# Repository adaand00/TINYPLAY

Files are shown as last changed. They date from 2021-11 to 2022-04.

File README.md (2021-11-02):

# TINYPLAY
A tiny (46x25mm) game console using the attiny5

## Development
 The code is fully contained in main.c. The code was compiled and uploaded with microchip studio, using the standard settings for "attiny5 release". The gerber files were made in fusion360.
 
 
 

## BOM
* PCB
* ATTINY5-TS
* 8 bit Shift register - TI: SN74HCS164DR
* cr2032 battery holder - Linx: BAT-HLD-001-THM-TR 
* SMD slide switch - C&K: JS102011SAQN 
* 15x 0805 red LEDs
* 2x 6x6mm tactile buttons
* sod123 diode
* various 0603 resistors and capacitors
 
 ## Future development
  - [ ] Make it smaller (!Important!)
  - [ ] Improve programming headers
  - [ ] Make the game more fun
  - [ ] Add more pixels

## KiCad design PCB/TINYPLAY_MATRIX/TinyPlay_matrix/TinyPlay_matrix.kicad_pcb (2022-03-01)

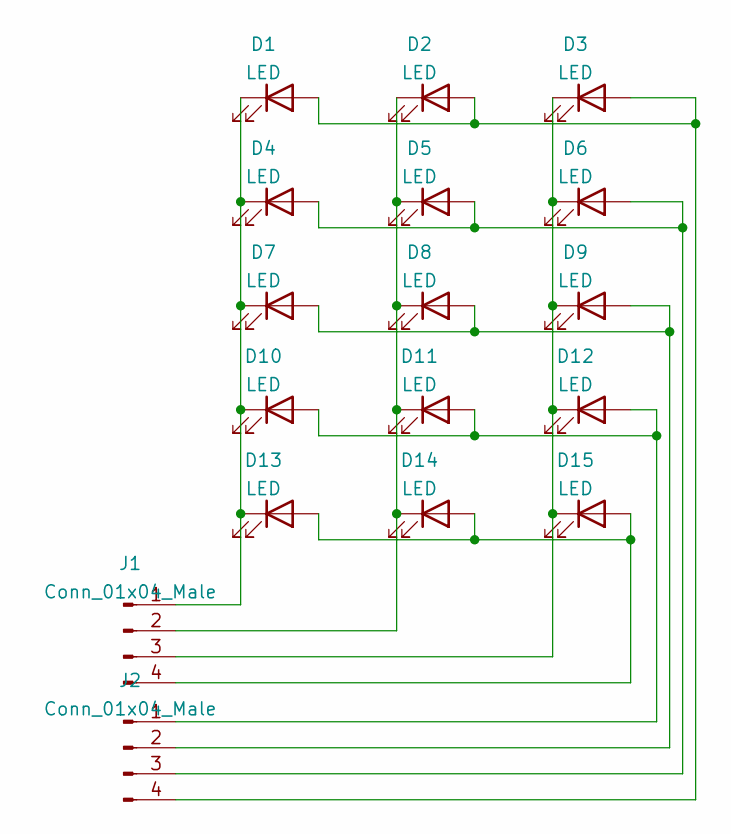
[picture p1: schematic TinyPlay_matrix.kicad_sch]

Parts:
D1, D2, D3, D4, D5, D6, D7, D8, D9, D10, D11, D12, D13, D14, D15: LED; LED_0603_1608Metric_Pad1.05x0.95mm_HandSolder
J1, J2: Conn_01x04_Male; PinHeader_1x04_P1.27mm_Vertical

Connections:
unnamed: D1.1 (K), D4.1 (K), D7.1 (K), D10.1 (K), D13.1 (K), J1.1
unnamed: D1.2 (A), D2.2 (A), D3.2 (A), J2.4
unnamed: D4.2 (A), D5.2 (A), D6.2 (A), J2.3
unnamed: D7.2 (A), D8.2 (A), D9.2 (A), J2.2
unnamed: D10.2 (A), D11.2 (A), D12.2 (A), J2.1
unnamed: D2.1 (K), D5.1 (K), D8.1 (K), D11.1 (K), D14.1 (K), J1.2
unnamed: D3.1 (K), D6.1 (K), D9.1 (K), D12.1 (K), D15.1 (K), J1.3
unnamed: D13.2 (A), D14.2 (A), D15.2 (A), J1.4

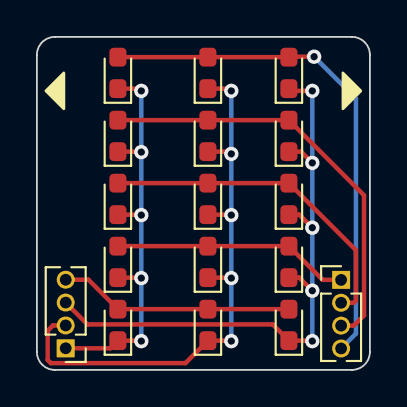
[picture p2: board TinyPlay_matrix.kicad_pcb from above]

Board: 2 copper layers, 18.5 x 18.5 mm, 17 parts (0 on the bottom side), 8 nets.

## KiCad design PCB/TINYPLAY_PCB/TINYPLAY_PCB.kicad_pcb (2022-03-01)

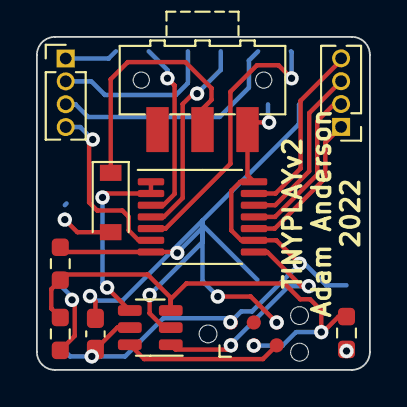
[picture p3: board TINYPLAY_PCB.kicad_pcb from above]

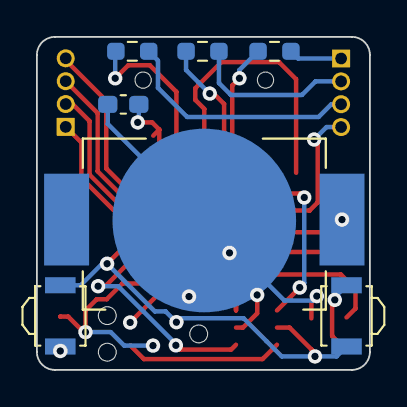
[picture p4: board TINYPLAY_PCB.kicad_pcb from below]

Board: 2 copper layers, 18.5 x 18.5 mm, 18 parts (7 on the bottom side), 21 nets.

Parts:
BT1: Battery_Cell; BAT_BAT-HLD-012-SMT
C1, C2: 100nF; C_0603_1608Metric_Pad1.08x0.95mm_HandSolder
D1: 1N4148W; D_SOD-123
J1: Conn_02x03_Odd_Even; Tag-Connect_TC2030-IDC-NL_2x03_P1.27mm_Vertical
J6, J7: Conn_01x04_Male; PinHeader_1x04_P1.27mm_Vertical
R1: 6.8k; R_0603_1608Metric_Pad0.98x0.95mm_HandSolder
R2: 15k; R_0603_1608Metric_Pad0.98x0.95mm_HandSolder
R3: 10k; R_0603_1608Metric_Pad0.98x0.95mm_HandSolder
R4, R5, R6: 1k; R_0603_1608Metric_Pad0.98x0.95mm_HandSolder
SW1: SW_SPDT; SW_SPDT_CK-JS102011SAQN
SW2, SW3: SW_Push; SW_SPST_B3U-3000P
U1: ATtiny5-TS; SOT-23-6
U2: 74HC164; TSSOP-14_4.4x5mm_P0.65mm

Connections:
/PB0: J1.1, U1.1 (PB0), U2.8 (CP)
/PB1: J1.3, R1.1, R2.1, R3.1, U1.3 (PB1)
/PB2: U1.4 (PB2), U2.1 (DSA), U2.2 (DSB)
/PB3: J1.5, U1.6 (~RESET/PB3)
GND: BT1.N, C1.2, C2.2, J1.6, R3.2, U1.2 (GND), U2.7 (GND)
unnamed: BT1.P2, D1.2 (A)
unnamed: D1.1 (K), SW1.2 (B)
unnamed: J6.1, R4.2
unnamed: J6.2, R5.2
unnamed: J6.3, R6.2
unnamed: J6.4, U2.6 (Q3)
unnamed: J7.1, U2.10 (Q4)
unnamed: J7.2, U2.11 (Q5)
unnamed: J7.3, U2.12 (Q6)
unnamed: J7.4, U2.13 (Q7)
unnamed: R1.2, SW2.1
unnamed: R2.2, SW3.1
unnamed: R4.1, U2.3 (Q0)
unnamed: R5.1, U2.4 (Q1)
unnamed: R6.1, U2.5 (Q2)
VDD: C1.1, C2.1, J1.2, SW1.1 (A), SW2.2, SW3.2, U1.5 (VCC), U2.9 (~MR), U2.14 (VCC)

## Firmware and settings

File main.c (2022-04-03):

/*
 * TinyPLay.c
 *
 * Created: 2021-08-28 18:41:26
 * Author : Adam
 */ 

#include <avr/io.h>
#define F_CPU 1000000UL
#include <util/delay.h>

#define DCLK 0
#define DDATA 2
#define BIN 1

unsigned char currentRow;
unsigned int numUpdates;

unsigned char rows[] = {0, 0b00010000, 0} ; 
unsigned char pressedright = 0;
unsigned char pressedleft = 0;
unsigned char playerPosition = 1;
unsigned char obsRow = 5;
unsigned char obsCol = 1;
unsigned char moved = 0;
unsigned char timeSincePress = 0;
unsigned char moveTime = 200;
unsigned char lastadd = 0;
volatile unsigned char endrows[] = {0b00010100, 0b00001000, 0b00010100};
unsigned char failed = 0;

int main( void )
{
	// set directions
	DDRB = 1<<DDATA | 1<<DCLK;
	// Disable digital input for button pin
	DIDR0 = 1<<BIN;
	// Set ADC pin	
	ADMUX = BIN;
	// Enable ADC and start conversion
	ADCSRA = 1<<ADEN | 1<<ADSC | 1<<ADATE | 0b100;
	

	// loop
	while (1)
	{
		_delay_ms(5);
		
		timeSincePress++;
		
		// Read analog input
		char butt = ADCL;
		char newpressedright;
		char newpressedleft;
		if(butt > 160){
			//both buttons pressed
			newpressedright = 1;	
			newpressedleft = 1;
		}else if(butt > 120){
			//right button pressed 				
			newpressedleft = 1;
			newpressedright = 0;	
		}else if(butt > 100){
			//left button pressed	
			newpressedleft = 0;
			newpressedright = 1;
		}else{
			//no button pressed
			newpressedright = 0;
			newpressedleft = 0;
		}
		
		//detect rising edge on left button
		if(newpressedleft & ~(pressedleft) & (playerPosition!=2)){
			playerPosition += 1;
			timeSincePress = 0;
		}
		
		//detect rising edge on right button
		if(newpressedright & ~(pressedright) & (playerPosition!=0)){
			playerPosition -= 1;
			timeSincePress = 0;
		}
		
		pressedright = newpressedright;
		pressedleft = newpressedleft;
		
		// Move obstacle down
		if(numUpdates++ > moveTime){
			
			rows[currentRow] = rows[currentRow] >> 1;
			moved++;
			
			
			
			// all rows have moved
			if(moved == 3){
				
				// detect obstacle
				if((rows[playerPosition] & 1))
				{
					failed = 1;
				}
				
				//reset counters
				moved = 0;
				numUpdates = 0;
				
				// Add new obstacle every n rows
				lastadd++;
				if(lastadd == 3){
					unsigned char row = timeSincePress & 0b11;
					if(row == 3){
						row = playerPosition;
					}
					rows[row] = rows[row] | 0b00100000;
					lastadd = 0;
					moveTime -= moveTime>>4;
				}
			}
		}
		
		
		// Draw column
		
		// Buffer layout:
		//  b7 < b6 < b5 < b4 < b3 < b2 < b1 < b0 
		//  R4 | R3 | R2 | R1 | R0 | C2 | C1 | C0
		//
		// Row source, column sink
		
		char buff = (rows[currentRow] | (playerPosition==currentRow))<<3 |((1<<currentRow)^0b00000111);
		buff = buff^0xFF;
		
		if (failed)
		{
			buff = 0b00000111;
		}
		
		// Serial shift out, highest bit first. 
		for(int i = 0; i < 8; i++)
		{
			// Set clock low
			PORTB &= ~(1<<DCLK);
			
			
			if(buff & 0x80){
				PORTB |= 1<<DDATA;
			}else{
				PORTB &= ~(1<<DDATA);
			}
			
			// Set clock High
			PORTB |= 1<<DCLK;

			buff = buff<<1;
		}
		
		// next row of multiplex
		if(++currentRow == 3)
		{
			currentRow = 0;
		}	
	}
}

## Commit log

2021-11-02 Add gerber files
2022-01-28 Start new version using kicad
    [TINYPLAY_PCB.kicad_pcb, TINYPLAY_PCB.kicad_sch, TinyPlay_matrix.kicad_pcb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]
2022-03-01 Version 2.0
    [TINYPLAY_PCB-B_Cu.gbr, TINYPLAY_PCB-B_Mask.gbr, TINYPLAY_PCB-B_Paste.gbr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]
